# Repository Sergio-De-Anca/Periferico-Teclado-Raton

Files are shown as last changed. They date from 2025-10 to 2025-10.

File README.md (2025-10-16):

## Periferico-Teclado-Raton
Este proyecto es un Trabajo de Fin de Grado, hecho en la Universidad de Sevilla en el “Grado
de Ingeniería Informática de Computadores” por Sergio Isidoro De Anca Garabito. Este trabajo se
realiza dentro del departamento de “Arquitectura y tecnología de computadores” y está tutorizado
por Juan Manuel Montes Sanchez y cotutorizado por Javier Civit Masot.

Consiste en la creación de un periférico con funciones de teclado-ratón que puede ser
utilizado con una sola mano. Para ello se utiliza un microcontrolador que maneja una serie de
componentes electrónicos como lo son “switches” o “joysticks”.

## Estructura del proyecto
- [Videos demostrativos](./FuncionamientoPrototipo) — En esta carpeta se encuentran imágenes del prototipo del periférico y vídeos sobre su funcionamiento.
- [Firmware](./ImplementacionConjunto) — Contiene el firmware completo del periférico
- [PCB](./PCB_TFG) — Contiene el esquemático y la huella de la PCB del periférico
- [Intento descriptor HID](./IntentoDescriptorHID/PerifericoTFG) — Contiene el intento de crear una librería para que el microcontrolador actue como un dispositivo HID y se concete por BLE al computador. **No funciona

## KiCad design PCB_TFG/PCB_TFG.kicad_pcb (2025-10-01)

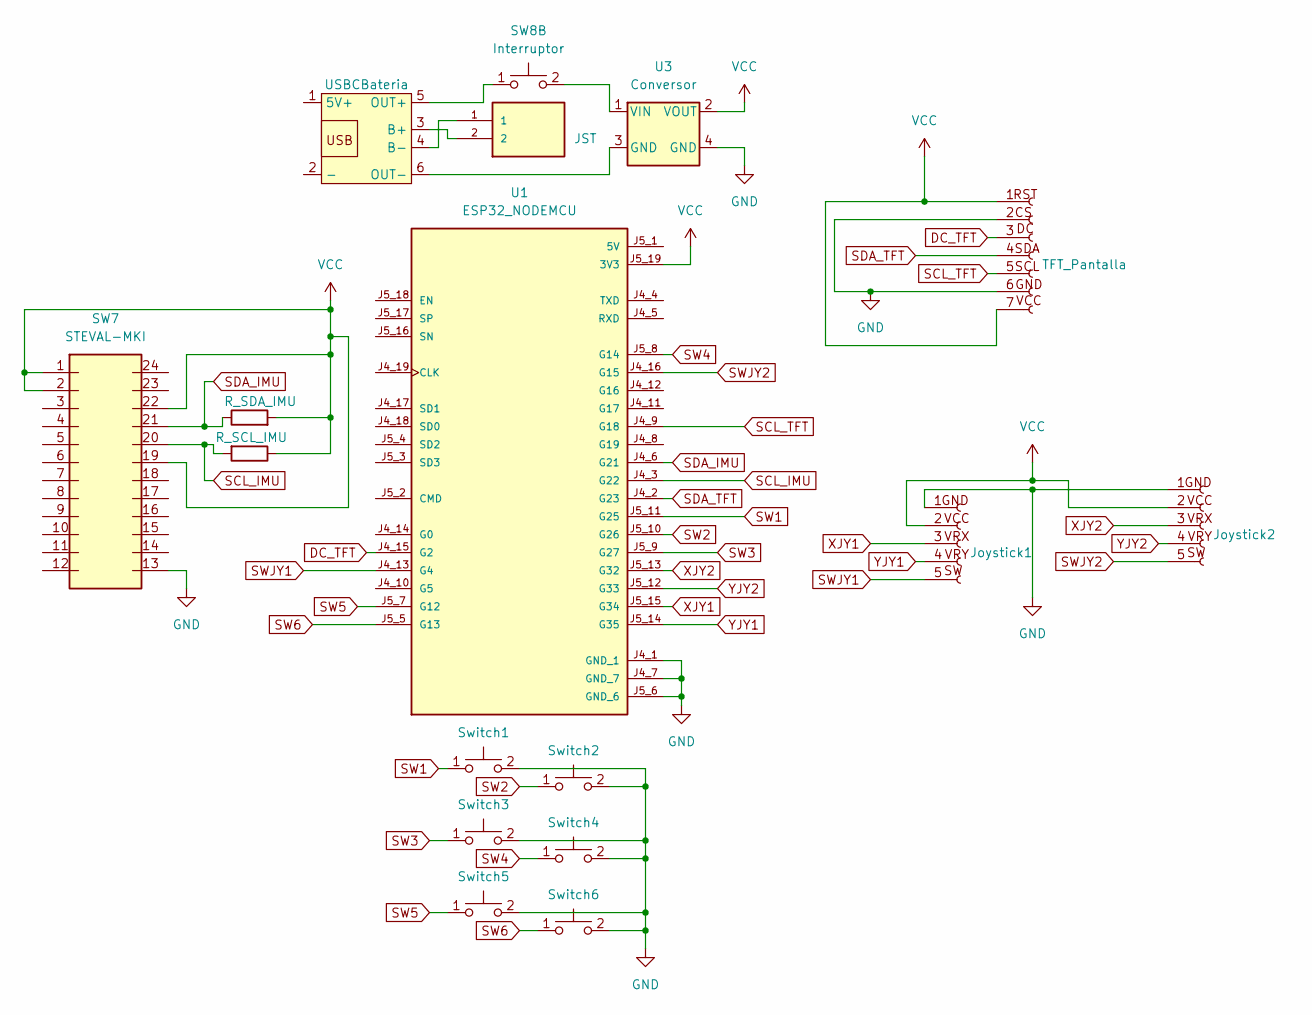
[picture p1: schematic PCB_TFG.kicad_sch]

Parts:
J1: JST; JST_S2B-PH-K-S_LF__SN_
J2: TFT_Pantalla; PinSocket_1x07_P2.54mm_Vertical
J3: Joystick1; PinHeader_1x05_P2.54mm_Vertical
J4: Joystick2; PinHeader_1x05_P2.54mm_Vertical
R1: R_SDA_IMU; R_Axial_DIN0204_L3.6mm_D1.6mm_P1.90mm_Vertical
R2: R_SCL_IMU; R_Axial_DIN0204_L3.6mm_D1.6mm_P1.90mm_Vertical
SW1: Switch1; SW_Cherry_MX_1.00u_Plate
SW2: Switch2; SW_Cherry_MX_1.00u_Plate
SW3: Switch3; SW_Cherry_MX_1.00u_Plate
SW4: Switch4; SW_Cherry_MX_1.00u_Plate
SW5: Switch5; SW_Cherry_MX_1.00u_Plate
SW6: Switch6; SW_Cherry_MX_1.00u_Plate
SW7: STEVAL-MKI; STEVAL-MKI229A
SW8: Interruptor; SW_DIP_SPSTx01_Slide_6.7x4.1mm_W7.62mm_P2.54mm_LowProfile
TP1: USBCBateria; TP4056-Module
U1: ESP32_NODEMCU; MODULE_ESP32_NODEMCU
U3: Conversor

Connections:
DC_TFT: J2.3, U1.J4_15 (G2)
GND: J2.2, J2.6, J3.1, J4.1, SW1.2 (D), SW2.2 (D), SW3.2 (D), SW4.2 (D), SW5.2 (D), SW6.2 (D), SW7.13 (GND), U1.J4_1 (GND_1), U1.J4_7 (GND_7), U1.J5_6 (GND_6), U3.4 (GND)
unnamed: SW8.1 (C), TP1.5 (OUT+)
unnamed: SW8.2 (D), U3.1 (VIN)
unnamed: J1.2, TP1.3 (B+)
unnamed: J1.1, TP1.4 (B-)
unnamed: TP1.6 (OUT-), U3.3 (GND)
SCL_IMU: R2.2, SW7.20 (SCL), U1.J4_3 (G22)
SCL_TFT: J2.5, U1.J4_9 (G18)
SDA_IMU: R1.1, SW7.21 (SDA), U1.J4_6 (G21)
SDA_TFT: J2.4, U1.J4_2 (G23)
SW1: SW1.1 (C), U1.J5_11 (G25)
SW2: SW2.1 (C), U1.J5_10 (G26)
SW3: SW3.1 (C), U1.J5_9 (G27)
SW4: SW4.1 (C), U1.J5_8 (G14)
SW5: SW5.1 (C), U1.J5_7 (G12)
SW6: SW6.1 (C), U1.J5_5 (G13)
SWJY1: J3.5, U1.J4_13 (G4)
SWJY2: J4.5, U1.J4_16 (G15)
VCC: J2.1, J2.7, J3.2, J4.2, R1.2, R2.1, SW7.1 (VDD), SW7.2 (VDDIO), SW7.19 (CS), SW7.22 (SDO), U1.J5_19 (3V3), U3.2 (VOUT)
XJY1: J3.3, U1.J5_15 (G34)
XJY2: J4.3, U1.J5_13 (G32)
YJY1: J3.4, U1.J5_14 (G35)
YJY2: J4.4, U1.J5_12 (G33)

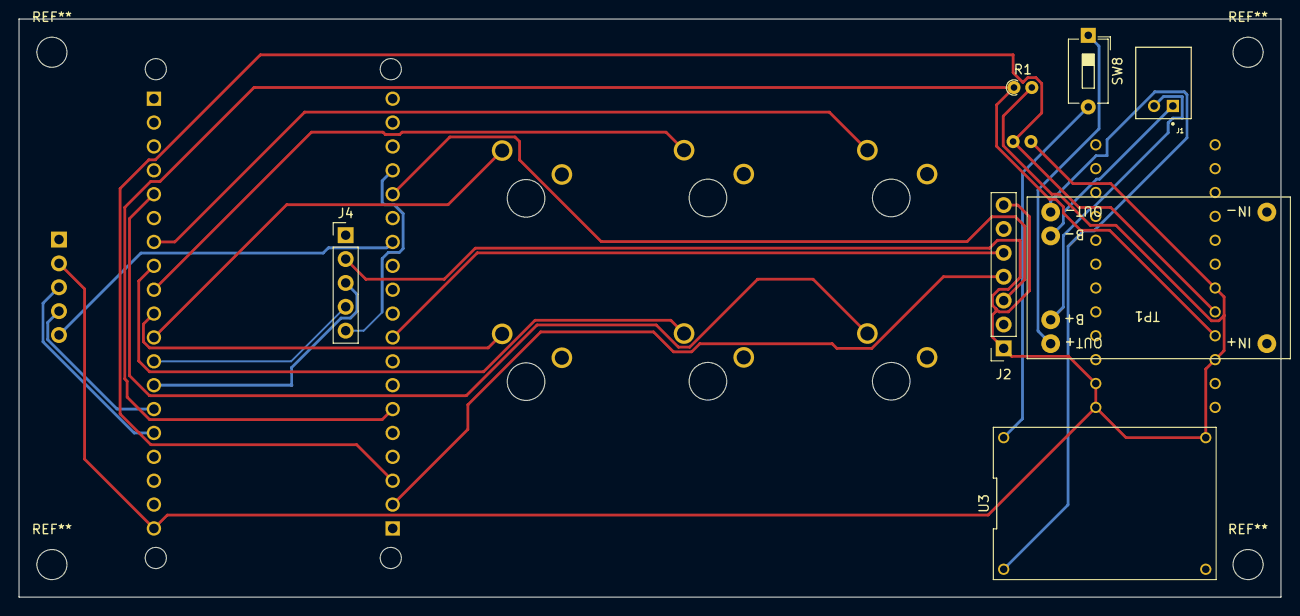
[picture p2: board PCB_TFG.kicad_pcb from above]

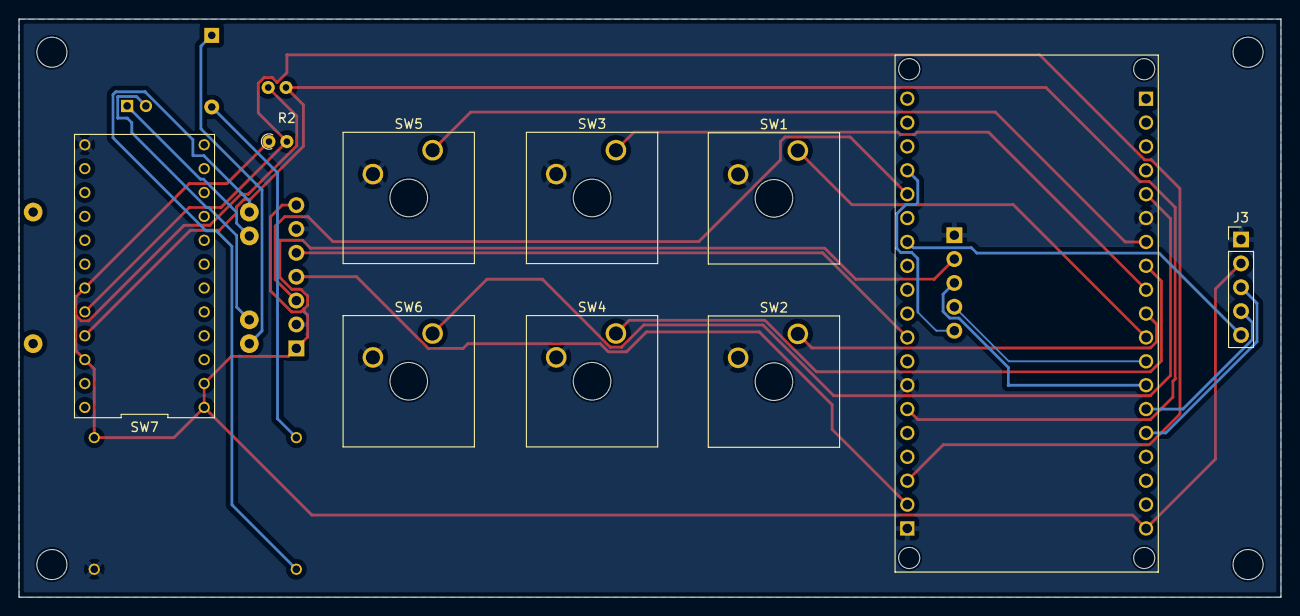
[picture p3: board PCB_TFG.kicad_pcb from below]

Board: 2 copper layers, 134.2 x 61.5 mm, 17 parts (10 on the bottom side), 24 nets.

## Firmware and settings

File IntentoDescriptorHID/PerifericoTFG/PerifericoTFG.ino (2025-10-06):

#include "DispositivoHID.h"

DispositivoHID dispositivoHID;


void setup() {
  Serial.begin(115200);
  delay(5000);
  dispositivoHID.inicializar();
  Serial.println("Inicializado");
}

void loop() {
  if (!dispositivoHID.deviceConnected) return;

  // 1. Pulsar y soltar una tecla (tecla "A", keycode 0x04)
  dispositivoHID.pulsarTecla(0x04);
  delay(100);
  dispositivoHID.soltarTecla();
  delay(500);

  // 2. Pulsar Ctrl + C
  dispositivoHID.pulsarTeclaModificada(0x01, 0x06);  // Ctrl + C
  delay(100);
  dispositivoHID.soltarTecla();
  delay(500);

  // 4. Mover ratón en diagonal (derecha + abajo)
  dispositivoHID.moverRaton(20, 20);
  delay(500);

  // 5. Click izquierdo
  dispositivoHID.clickIzquierdo();
  delay(500);

  // 6. Click derecho
  dispositivoHID.clickDerecho();
  delay(500);

  // 7. Scroll hacia abajo (−1)
  dispositivoHID.scrollRueda(-1);
  delay(300);

  // 8. Scroll hacia arriba (+3)
  dispositivoHID.scrollRueda(+3);
  delay(300);

  // 9. Mantener tecla "W" presionada (ej. para un juego)
  dispositivoHID.mantenerTecla(0x1A);  // W
  delay(1000);                         // Mantener 1s
  dispositivoHID.soltarTecla();
  delay(500);

  // Repetir solo una vez
  delay(1000);  // Detener el loop

  Serial.println("Iteración completada");
  
}

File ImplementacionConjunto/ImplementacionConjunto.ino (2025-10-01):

#include "ControladorIMU.h"
#include "ControladorTeclado.h"
#include "ControladorPantalla.h"
#include <BleCombo.h>

void setup() {
  Serial.begin(115200);
  delay(500); 
  /***Inicialización BLE_HID***/
  Serial.println("Starting BLE work!");
  Keyboard.begin();
  Mouse.begin();
  delay(500);
  /***Inicialización del sensor IMU***/
  inicializarIMU();
  /***Inicialización interrupciones***/
  inicializarInterrupcionesTeclado();
  inicializarPantalla();
  /***Inicialización tareas***/
  // Tarea raton en núcleo 0
  xTaskCreatePinnedToCore(Raton, "Raton", 2048, NULL, 1, NULL, 0);
  // Tarea teclado en núcleo 1
  xTaskCreatePinnedToCore(Teclado, "Teclado", 2048, NULL, 1, NULL, 1);
  // Tarea pantalla en núcleo 1
  xTaskCreatePinnedToCore(Pantalla, "Pantalla", 2048, NULL, 1, NULL, 1);
}

void loop(){
}

void Teclado(void *pvParameters) {
  while (1) {
    
    // Joysticks
    Joystick(EjexJy1, EjeyJy1, ruletaJy1, 1);
    Joystick(EjexJy2, EjeyJy2, ruletaJy2, 2);
    // Clicks raton
    clickIzquierdo();
    clickDerecho();
    //Teclas
    espacio();
    back();
    shiftIzquierdo();
    ctrlIzquierdo();

    vTaskDelay(100 / portTICK_PERIOD_MS);
  }
}

void Pantalla(void *pvParameters) {
  while (1) {
    //Muestra ruleta al clicar el joystick
    if (flagJy1) {
      flagJy1 = false;  // reseteo el flag
      Serial.println("La ruleta 1 es ahora: " + String(ruletaJy1));
      if(ruletaJy1 == 0){
        dibujarCaracteres(ruleta1_0, 11);
      }else if (ruletaJy1 == 1){
        dibujarCaracteres(ruleta1_1, 11, 10);
      }else if (ruletaJy1 == 2){
        dibujarCaracteres(ruleta1_2, 11);
      }
    }else if (flagJy2){
      flagJy2 = false; 
      Serial.println("La ruleta 2 es ahora: " + String(ruletaJy2));
      if(ruletaJy2 == 0){
        dibujarCaracteres(ruleta2_0, 11);
      }else if (ruletaJy2 == 1){
        dibujarCaracteres(ruleta2_1, 11);
      }else if (ruletaJy2 == 2){
        dibujarCaracteres(ruleta2_2, 11);
      }
    }
    vTaskDelay(100 / portTICK_PERIOD_MS);
  }
}

void Raton(void *pvParameters) {
  while (1) {
    if(Keyboard.isConnected()){
      moverRatonSuavizado();
    }
    vTaskDelay(10 / portTICK_PERIOD_MS);
  }
}

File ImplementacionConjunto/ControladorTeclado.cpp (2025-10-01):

#include "ControladorTeclado.h"

// Constantes de joystick
const int DEADZONE = 800;
const int center = 4096 / 2;

//Banderas interrupciones
volatile bool jy1Activo = false;
volatile bool jy2Activo = false;

//Banderas interrupciones 
volatile bool flagClickIzq = false;
volatile bool flagClickDer = false;
volatile bool flagEspacio = false;
volatile bool flagBack = false;
volatile bool flagShift = false;
volatile bool flagCtrl = false;

 //Valores de la ruleta
volatile int ruletaJy1 = 0;
volatile int ruletaJy2 = 0;

const uint8_t ruleta1_0[] = {'a', 'e', 'i', 'o', 'u', 0x28/*ENTER*/, KEY_BACKSPACE, KEY_DELETE};
const uint8_t ruleta1_1[] = {'0', '1', '2', '3', '4', '5', '6', '7', '8', '9'};
const uint8_t ruleta1_2[] = {'<', ',', '.', '-', '+', 'º', '?', '¡'};

const uint8_t ruleta2_0[] = {'b', 'c', 'd', 'f', 'g', 'h', 'j', 'k'};
const uint8_t ruleta2_1[] = {'l', 'm', 'n', 'p', 'q', 'r', 's', 't'};
const uint8_t ruleta2_2[] = {'v', 'w', 'x', 'y', 'z', KEY_INSERT, KEY_BACKSPACE, KEY_DELETE};

//Evitar debounce en ruletas
volatile unsigned long lastDebounceTimeJy1 = 0;
volatile unsigned long lastDebounceTimeJy2 = 0;
const unsigned long debounceDelay = 150; // milisegundos

//Bandera para modificar pantalla cuando se pulsa la ruleta
volatile bool flagJy1 = false;  // global
volatile bool flagJy2 = false;  // global
 
  /*******************************************/
  /***Inicialización pines e interrupciones***/
  /*******************************************/

void inicializarInterrupcionesTeclado(){

    //Inicializo pines teclas
    pinMode(CLICK_IZQ_PIN, INPUT_PULLUP);
    pinMode(CLICK_DER_PIN, INPUT_PULLUP);

    pinMode(TECLA_ESPACIO_PIN, INPUT_PULLUP);
    pinMode(TECLA_BACK_PIN, INPUT_PULLUP);
    pinMode(TECLA_SHIFT_PIN, INPUT_PULLUP);
    pinMode(TECLA_CTRL_IZQ_PIN, INPUT_PULLUP);

    // Inicializa pines joysticks
    pinMode(EjexJy1, INPUT);
    pinMode(EjeyJy1, INPUT);
    pinMode(EjexJy2, INPUT);
    pinMode(EjeyJy2, INPUT);
    pinMode(SWITCH_JY1_PIN, INPUT_PULLUP);
    pinMode(SWITCH_JY2_PIN, INPUT_PULLUP);
    
    //Vincula cada tecla y Joystick a su interrupcion (incluido clics raton)
    attachInterrupt(digitalPinToInterrupt(CLICK_IZQ_PIN), ISR_ClickIzq, CHANGE);
    attachInterrupt(digitalPinToInterrupt(CLICK_DER_PIN), ISR_ClickDer, CHANGE);
    
    attachInterrupt(digitalPinToInterrupt(TECLA_ESPACIO_PIN), ISR_TeclaEspacio, CHANGE);
    attachInterrupt(digitalPinToInterrupt(TECLA_BACK_PIN), ISR_TeclaBack, CHANGE);
    attachInterrupt(digitalPinToInterrupt(TECLA_SHIFT_PIN), ISR_TeclaShift, CHANGE);
    attachInterrupt(digitalPinToInterrupt(TECLA_CTRL_IZQ_PIN), ISR_TeclaCtrlIzq, CHANGE);
    
    attachInterrupt(digitalPinToInterrupt(SWITCH_JY1_PIN), ISR_PulsacionJy1, FALLING);
    attachInterrupt(digitalPinToInterrupt(SWITCH_JY2_PIN), ISR_PulsacionJy2, FALLING);
}
  /*****************************************/
  /***Funciones asociadas a los Joysticks***/
  /*****************************************/
//Calcular hacia que dirección apunta el Joystick
int calcularDireccion(int x, int y, int totaldirecciones = 8) {
  float angulo = atan2(y, x); // ángulo en radianes
  if (angulo < 0) angulo += 2 * PI; // normaliza a 0–2π

  int direccion = ((int)round((angulo / (2 * PI)) * totaldirecciones)) % totaldirecciones;
  return direccion; // valores de 0 a 7
}
//Escribir la tecla en el pc y mostrar la que se señala en la pantalla TFT
void escribirTecla(int x, int y, int ruleta, int Joystick){

  uint8_t caracter = ' ';
  int dir = calcularDireccion(x, y);
  if (Joystick == 1){
    switch(ruleta){
      case 0: 
        caracter = ruleta1_0[dir];  
        dibujarCaracteres(ruleta1_0, dir);
        break;
      case 1: 
        dir = calcularDireccion(x, y, 10);
        caracter = ruleta1_1[dir];  
        dibujarCaracteres(ruleta1_1, dir, 10);
        break;
      case 2: 
        caracter = ruleta1_2[dir];
        dibujarCaracteres(ruleta1_2, dir);
        break;
      default: break;
    }  
  }else if (Joystick == 2){
    switch(ruleta){
      case 0: 
        caracter = ruleta2_0[dir];
        dibujarCaracteres(ruleta2_0, dir);
        break;
      case 1: 
        caracter = ruleta2_1[dir];
        dibujarCaracteres(ruleta2_1, dir);
        break;
      case 2: 
        caracter = ruleta2_2[dir];
        dibujarCaracteres(ruleta2_2, dir);
        break;
      default: break;
    }
  }  
  
  Serial.println("La direccion seleccionada es: "+ String(dir));
  Serial.println("La tecla que va a escribit es: "+ String((char)caracter));
  
  if (Keyboard.isConnected()) {
      Keyboard.press(caracter);
      delay(5);
      Keyboard.release(caracter);
    }else{
      Serial.println("El teclado no esta conectado");
    }
}
//Calcula si el joystick se ha movido
bool fueraDeCentro(int x, int y) {
  return !(x * x + y * y < DEADZONE * DEADZONE) ; // Verificar zona muerta  
}
//Mira si se esta utilizando un Jy y si es así, se va a escribir tecla
void Joystick(int EjeX, int EjeY, int ruletaJy, int Joystick){
    int x = analogRead(EjeX);
    int y = analogRead(EjeY);
    //Serial.println("El eje x es: " + String(x) + " El eje y es: " + String(y));
    int dx = static_cast<int>(x) - center; //Ahora el valor esta entre -2048 y 2048
    int dy = static_cast<int>(y) - center; //Ahora el valor esta entre -2048 y 2048
    //Serial.println("El eje dx es : "+ String(dx) + " El eje dy es:"+ String(dy));

    if (fueraDeCentro(dx, dy)){
      if (!jy1Activo) {
        jy1Activo = true;
        escribirTecla(dx, dy, ruletaJy, Joystick);  // Interrupción simulada
      } else {
        jy1Activo = false;  // Vuelve a estar en centro
      }
    }
}
  /***************************************/
  /***Interrupciones de las pulsaciones***/
  /***************************************/
void IRAM_ATTR ISR_PulsacionJy1() {
  unsigned long now = millis();
  if (now - lastDebounceTimeJy1 > debounceDelay) {
    ruletaJy1++;
    if (ruletaJy1 > 2) ruletaJy1 = 0;
    lastDebounceTimeJy1 = now;
    flagJy1= true;
  }
}
void IRAM_ATTR ISR_PulsacionJy2() {
  unsigned long now = millis();
  if (now - lastDebounceTimeJy2 > debounceDelay) {
    ruletaJy2++;
    if (ruletaJy2 > 2) ruletaJy2 = 0;
    lastDebounceTimeJy2 = now;
    
    flagJy2 = true;
  }
}

void IRAM_ATTR ISR_ClickIzq() {
  flagClickIzq = true;
}
void IRAM_ATTR ISR_ClickDer() {
  flagClickDer = true;
}
void IRAM_ATTR ISR_TeclaEspacio() {
  flagEspacio = true;
}
void IRAM_ATTR ISR_TeclaBack() {
  flagBack = true;
}
void IRAM_ATTR ISR_TeclaShift() {
  flagShift = true;
}
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

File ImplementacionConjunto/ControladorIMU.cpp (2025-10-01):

#include "ControladorIMU.h"

LSM6DSO myIMU; // I2C, dirección 0x6B
const float UMBRAL_GIRO = 5.0f;  // Umbral mínimo para movimiento (dps)
const float FACTOR_SENSIBILIDAD = 0.30f; // Ajusta la sensibilidad del ratón

// Variables para filtro paso bajo
float filtroX = 1.0f;
float filtroY = 1.0f;
float filtroZ = 1.0f;
const float ALFA = 0.8f; // factor de suavizado 

int orientacionActual;
int orientacionAnterior;

void inicializarIMU() {
  Wire.begin();
  delay(10);
  
  if (myIMU.begin()) {
    Serial.println("Ready.");
  } else {
    Serial.println("Could not connect to IMU.");
    Serial.println("Freezing");
    while (1); // Congela si falla
  }

  if (myIMU.initialize(BASIC_SETTINGS)) {
    Serial.println("Loaded Settings.");
  }
}
  /*********************************/
  /***Mueve el raton por pantalla***/
  /*********************************/
void moverRatonSuavizado() {
    // Leer velocidades angulares (dps)
    float gx = myIMU.readFloatGyroX();
    float gy = myIMU.readFloatGyroY();
    float gz = myIMU.readFloatGyroZ();
    // Aplicar filtro paso bajo para suavizar
    filtroX = ALFA * gx + (1 - ALFA) * filtroX;
    filtroY = ALFA * gy + (1 - ALFA) * filtroY;
    filtroZ = ALFA * gz + (1 - ALFA) * filtroZ;
    // Ignorar movimientos muy pequeños (ruido)
    if (abs(filtroX) < UMBRAL_GIRO) filtroX = 0;
    if (abs(filtroY) < UMBRAL_GIRO) filtroY = 0;
    if (abs(filtroZ) < UMBRAL_GIRO) filtroZ = 0;
    // Mapear velocidades del giroscopio a movimientos del ratón
    int moveX = int(filtroZ * FACTOR_SENSIBILIDAD);  // Giros Z → desplazamiento X del ratón (horizontal)
    int moveY = int(-filtroX * FACTOR_SENSIBILIDAD); // Giros X → desplazamiento Y del ratón (vertical) (invertido)
    int wheel = int(filtroY * 0.05);              // Giros Y → rueda del ratón (scroll)
    // Solo mover si hay movimiento significativo
    if (moveX != 0 || moveY != 0 || wheel != 0) {
        Mouse.move(-moveX, moveY, wheel);
    }
}
  /************************************/
  /***Muestra orientacion del sensor***/
  /************************************/
void mostrarOrientacion(int orientacionActual) {
  if (orientacionActual != 0) {
    orientacionAnterior = orientacionActual;
  }
  Serial.print("\nDirección de giro anterior: ");
  Serial.println(orientacionAnterior);
  Serial.print("\nDirección de giro actual: ");
  Serial.println(orientacionActual);
}
  /****************************************************************************/
  /***Funciones para obtener datos de acelerometro, giroscopio y temperatura***/
  /****************************************************************************/
static void leerAcelerometro() {
  Serial.print("\nAccelerometer:\n");
  Serial.print(" X = ");
  Serial.println(myIMU.readFloatAccelX(), 3);
  Serial.print(" Y = ");
  Serial.println(myIMU.readFloatAccelY(), 3);
  Serial.print(" Z = ");
  Serial.println(myIMU.readFloatAccelZ(), 3);
}
static void leerGiroscopio() {
  Serial.print("\nGyroscope:\n");
  Serial.print(" X = ");
  Serial.println(myIMU.readFloatGyroX(), 3);
  Serial.print(" Y = ");
  Serial.println(myIMU.readFloatGyroY(), 3);
  Serial.print(" Z = ");
  Serial.println(myIMU.readFloatGyroZ(), 3);
}
static void leerTemperatura() {
  Serial.print("\nThermometer:\n");
  Serial.print(" Degrees F = ");
  Serial.println(myIMU.readTempF(), 3);
}
void leerYMostrarDatosIMU() {
  leerAcelerometro();
  leerGiroscopio();
  leerTemperatura();
}

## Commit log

2025-10-01 Añadido diseño de la PCB
    [PCB_TFG.kicad_pcb, PCB_TFG.kicad_sch]
2025-10-06 Añadido Intento del descriptor HID y el funcionamiento del prototipo
